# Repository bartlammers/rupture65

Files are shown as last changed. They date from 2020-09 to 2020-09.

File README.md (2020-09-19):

# Rupture65, a split 65% keyboard

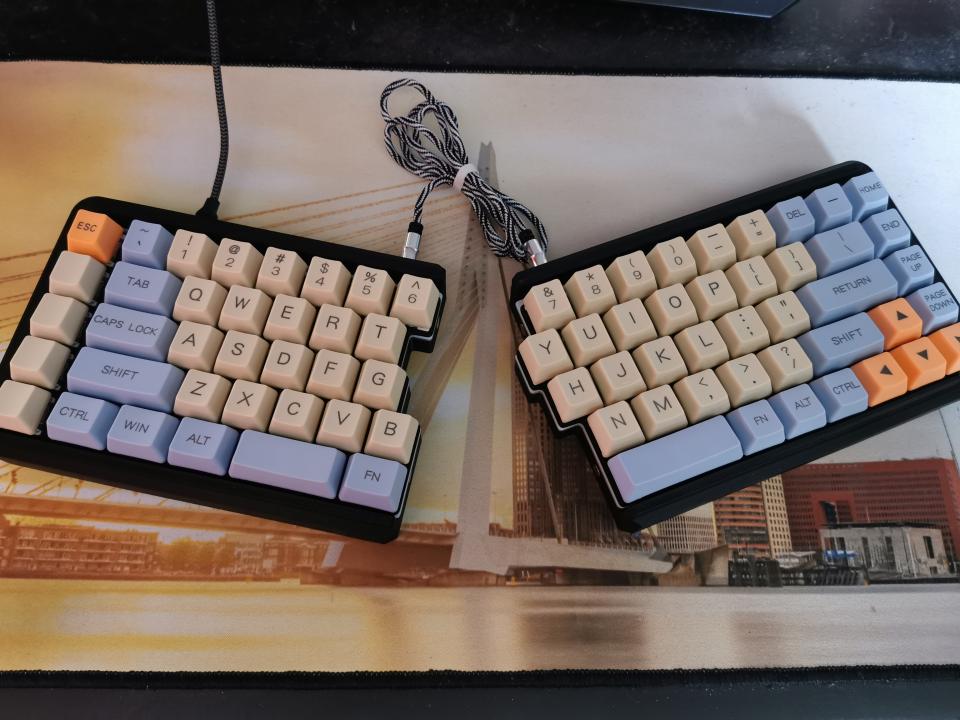
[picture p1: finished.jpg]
Finished Keyboard


## Left

[Project](./Left)  
[iBom](http://htmlpreview.github.io/?https://github.com/bartlammers/rupture65/blob/master/Left/bom/ibom.html)

## Right

[Project](./Right)  
[iBom](http://htmlpreview.github.io/?https://github.com/bartlammers/rupture65/blob/master/Right/bom/ibom.html)

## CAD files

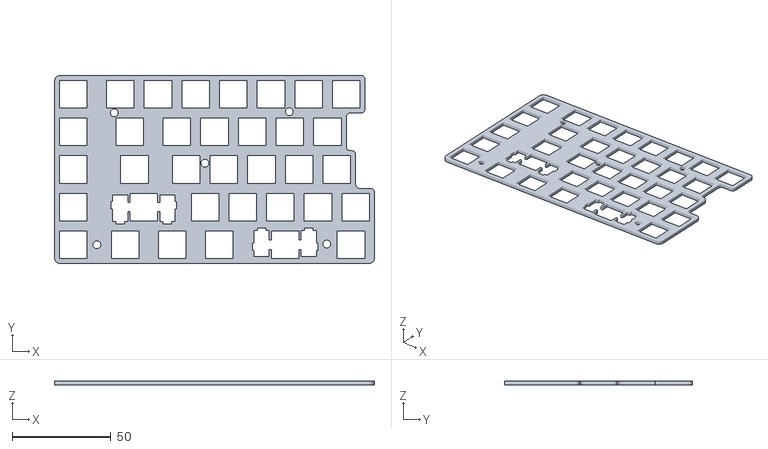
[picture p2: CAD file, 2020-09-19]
Plate/Left.stl
161.9 x 95.3 x 2.00

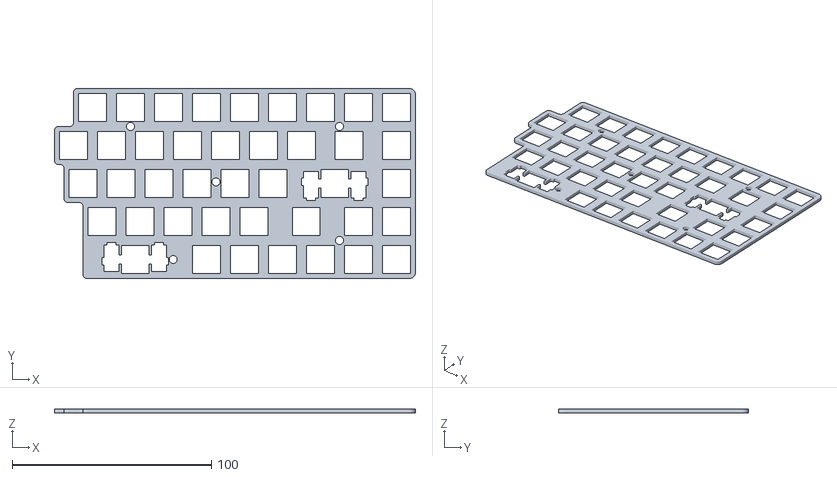
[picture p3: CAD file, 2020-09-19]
Plate/Right.stl
181.0 x 95.3 x 2.00

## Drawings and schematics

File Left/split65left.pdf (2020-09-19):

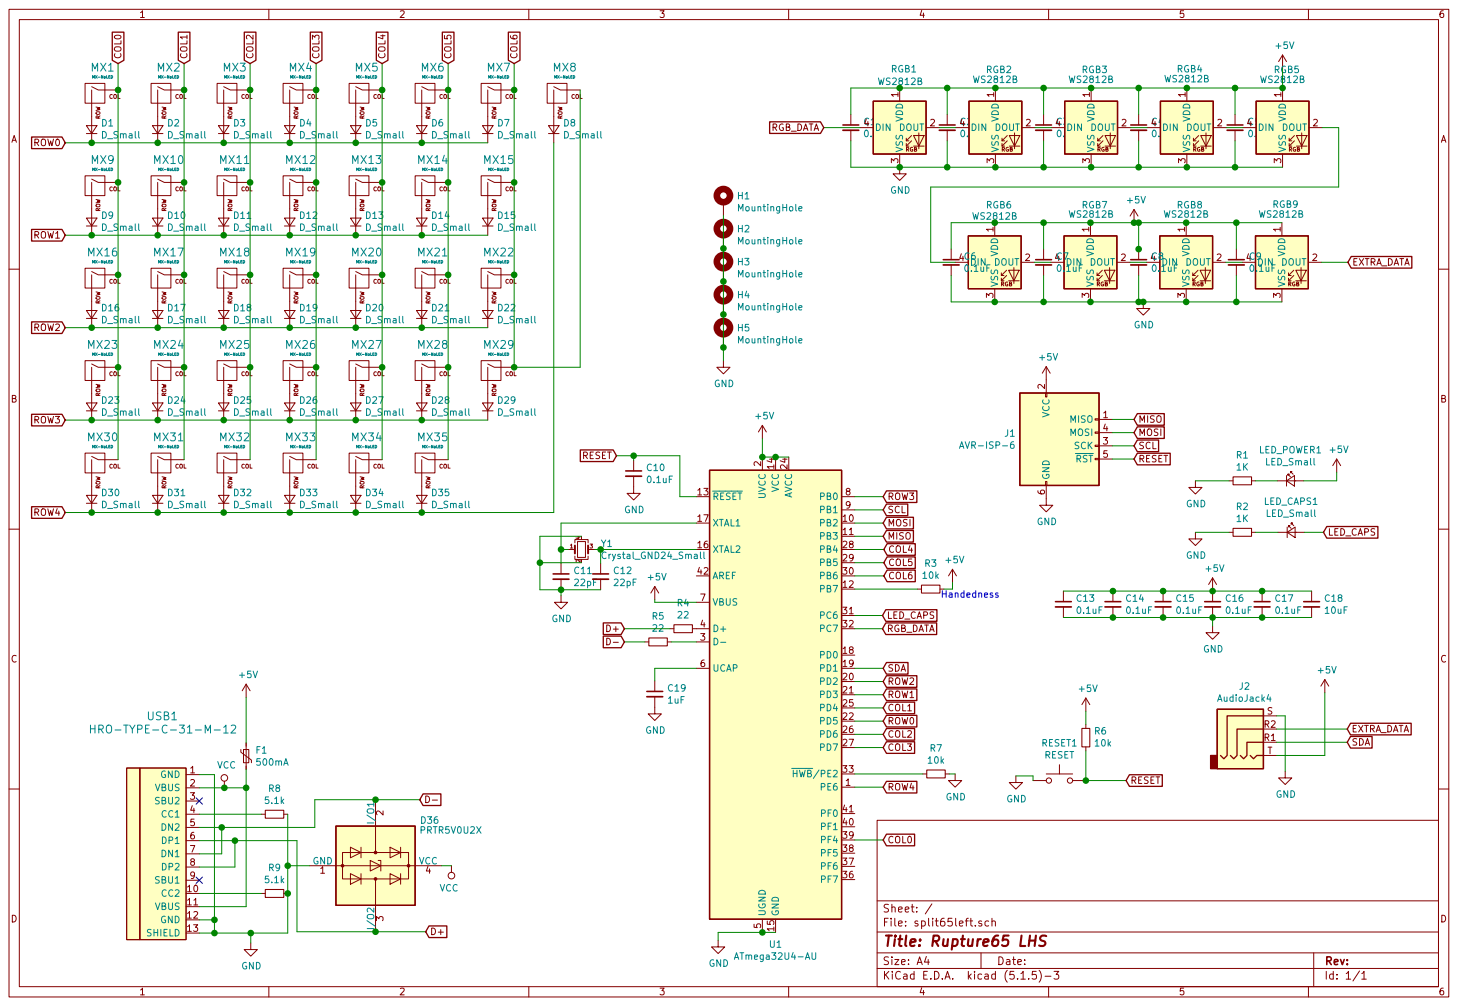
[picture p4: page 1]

MX-NoLED D7D_Small COL ROW MX6

MX-NoLED D4D_Small COL ROW MX24
MX-NoLED D16 D_Small COL ROW MX16

3 DIN 4 RGB8 WS2812B D24 D_Small COL ROW MX9
MX-NoLED D30 D_Small COL ROW MX30

MX-NoLED D13 D_Small COL ROW MX12

MX-NoLED D14 D_Small COL ROW MX13

MX-NoLED D20 D_Small COL ROW MX19

MX-NoLED D23 D_Small COL ROW MX23

2 SCK 3 MOSI 4 RST 5 GND

MX-NoLED D32 D_Small COL ROW MX31

MX-NoLED D34 D_Small COL ROW MX33

MX-NoLED D35 D_Small COL ROW MX34

2 PD2 20 PD3 21 PD5 22 AVCC 24 PD4 25 PD6 26 PD7 27 PB4 28 PB5 29 D- 3 PB6 30 PC6 31 PC7 32 HWB/PE2 33 PF7 36 PF6 37 PF5 38 PF4 39 D+ 4 PF1 40 PF0 41 AREF 42 UGND

5 UCAP 6 VBUS 7 PB0 8 PB1 9 U1 ATmega32U4-AU GND

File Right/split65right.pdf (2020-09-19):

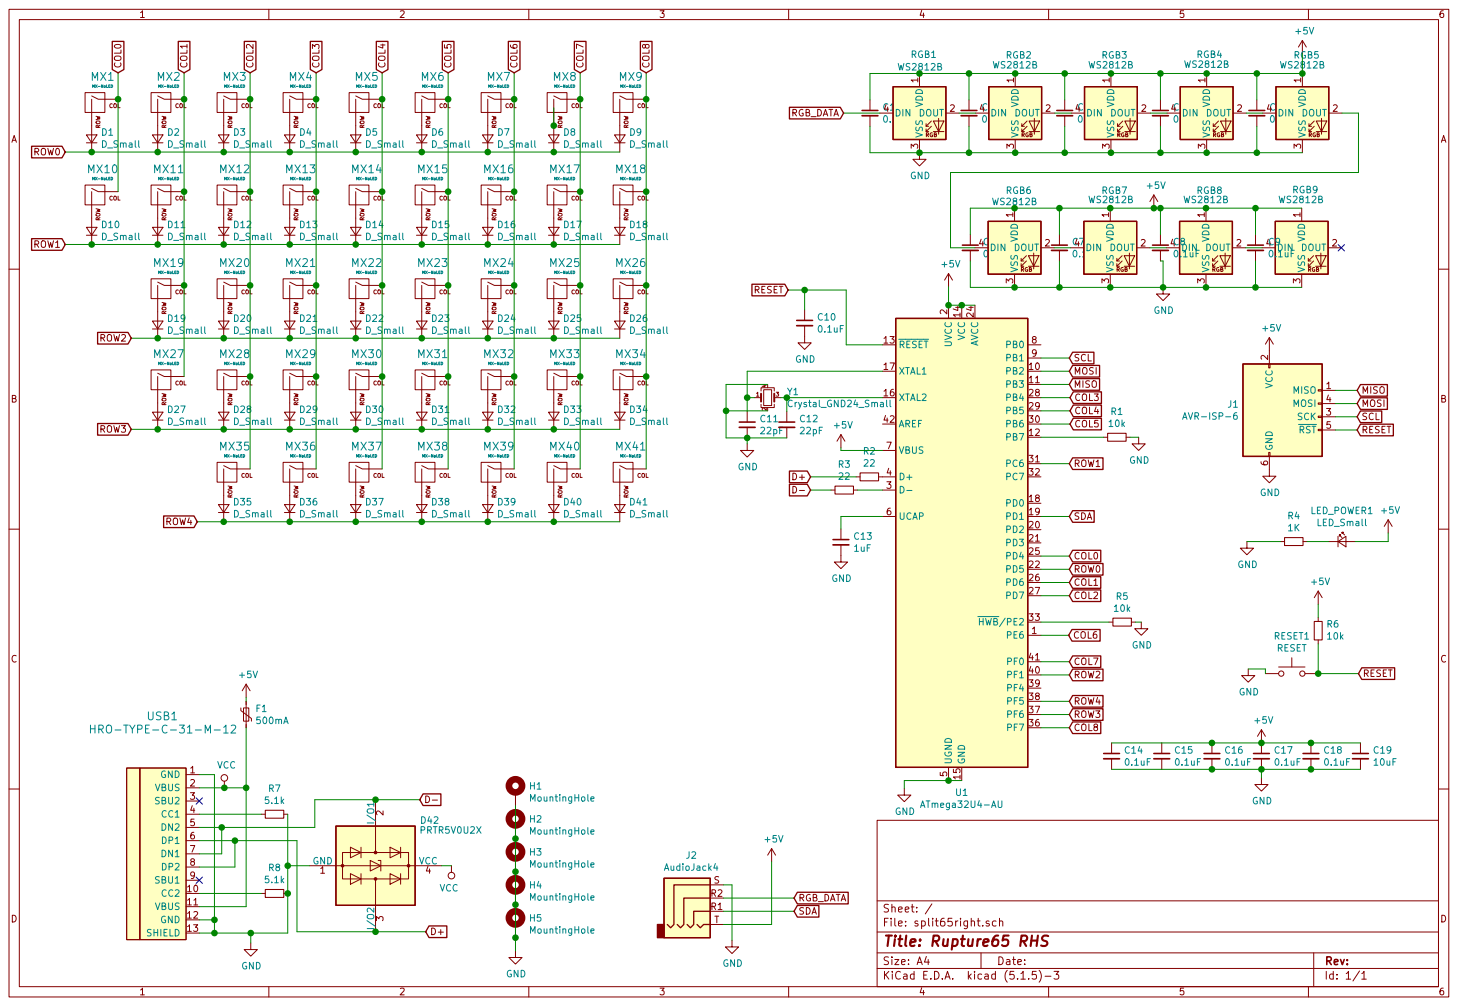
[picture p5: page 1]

MX-NoLED D2D_Small COL ROW MX1

MX-NoLED D3D_Small COL ROW MX2

MX-NoLED D4D_Small COL ROW MX3

+5V D5D_Small COL ROW MX4
MX-NoLED D14 D_Small COL ROW MX13

MX-NoLED D6D_Small COL ROW MX5

MX-NoLED D17 D_Small COL ROW MX8

MX-NoLED D11 D_Small COL ROW MX10

MX-NoLED COL ROW MX11

MX-NoLED D13 D_Small COL ROW MX12

MX-NoLED D16 D_Small COL ROW MX14

MX-NoLED D25 D_Small COL ROW MX16

MX-NoLED D26 D_Small COL ROW MX17

MX-NoLED D21 D_Small COL ROW MX20

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

MX-NoLED COL ROW MX27

MX-NoLED D41 D_Small D28 D_Small COL ROW MX28

2 SCK 3 MOSI 4 RST 5 GND

MX-NoLED COL ROW MX35

MX-NoLED D40 D_Small COL ROW MX38

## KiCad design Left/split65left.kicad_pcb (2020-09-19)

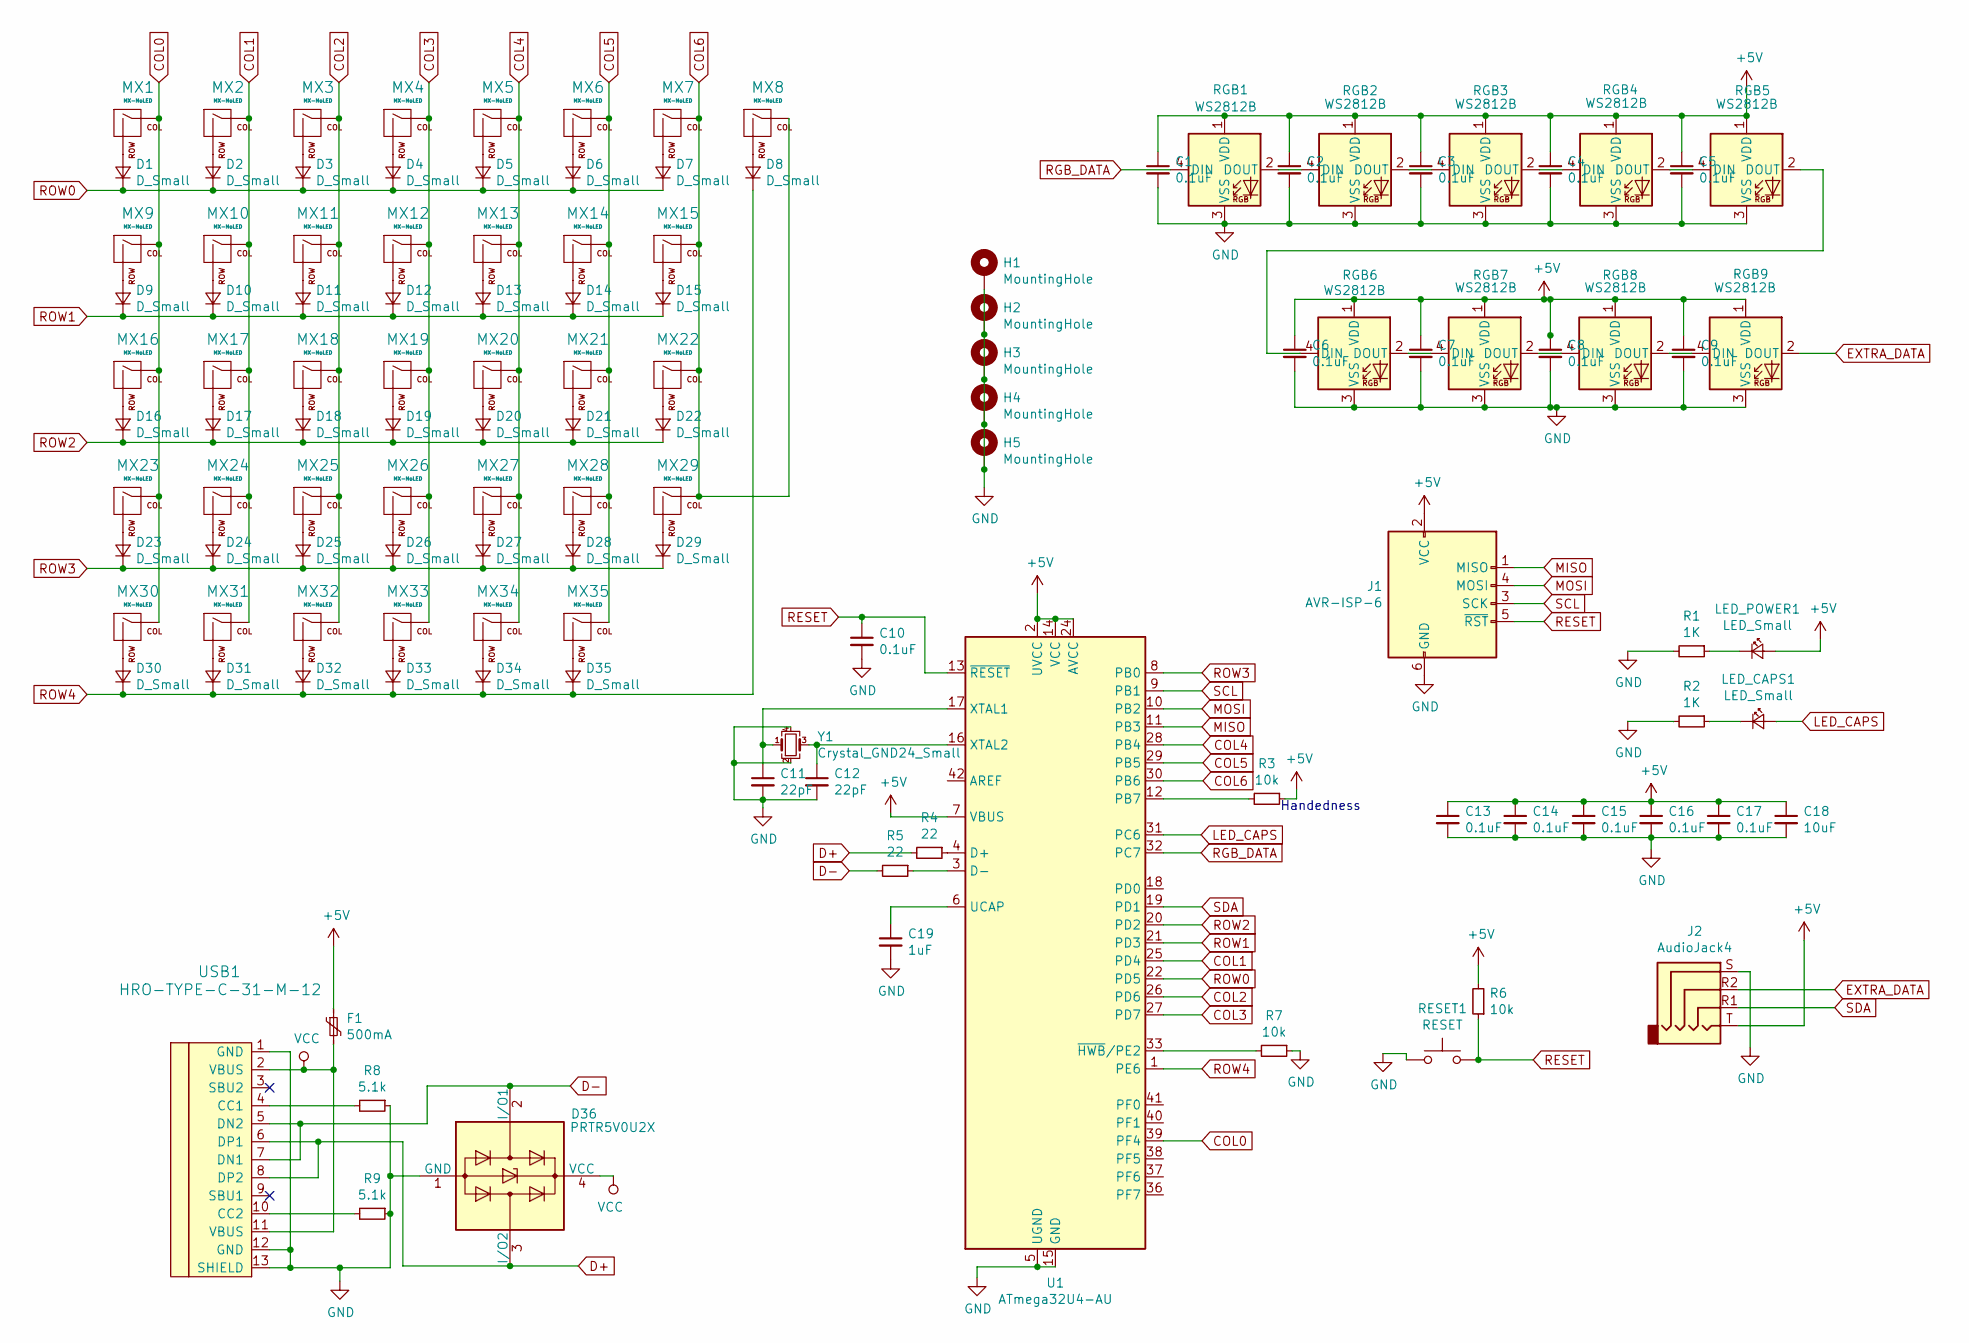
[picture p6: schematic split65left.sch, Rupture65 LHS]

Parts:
C1, C2, C3, C4, C5, C6, C7, C8, C9, C10, C13, C14, C15, C16, C17: 0.1uF; C_0805_2012Metric_Pad1.15x1.40mm_HandSolder
C11, C12: 22pF; C_0805_2012Metric_Pad1.15x1.40mm_HandSolder
C18: 10uF; C_0805_2012Metric_Pad1.15x1.40mm_HandSolder
C19: 1uF; C_0805_2012Metric_Pad1.15x1.40mm_HandSolder
D1, D2, D3, D4, D5, D6, D7, D8, D9, D10, D11, D12, D13, D14, D15, D16, D17, D18, D19, D20, D21, D22, D23, D24, D25, D26, D27, D28, D29, D30, D31, D32, D33, D34, D35: D_Small; D_SOD123_hand
D36: PRTR5V0U2X; SOT-143
F1: 500mA; Fuse_1206_3216Metric_Pad1.42x1.75mm_HandSolder
H1, H2, H3, H4, H5: MountingHole; MountingHole_2.2mm_M2_Pad_Via
J1: AVR-ISP-6; PinHeader_2x03_P2.54mm_Vertical
J2: AudioJack4; PJ-3200B-4A
LED_CAPS1: LED_Small; LED_0805_2012Metric
LED_POWER1: LED_Small; LED_0805_2012Metric
MX1, MX2, MX3, MX4, MX5, MX6, MX7, MX8, MX9, MX11, MX12, MX13, MX14, MX15, MX16, MX18, MX19, MX20, MX21, MX22, MX23, MX25, MX26, MX27, MX28, MX29, MX30: MX-NoLED; SW_Cherry_MX_1.00u_PCB
MX10: MX-NoLED; SW_Cherry_MX_1.50u_PCB
MX17: MX-NoLED; SW_Cherry_MX_1.75u_PCB
MX24: MX-NoLED; SW_Cherry_MX_2.25u_PCB
MX31, MX32, MX33, MX35: MX-NoLED; SW_Cherry_MX_1.25u_PCB
MX34: MX-NoLED; SW_Cherry_MX_2.25u_PCB_flippedstab
R1, R2: 1K; R_0805_2012Metric_Pad1.15x1.40mm_HandSolder
R3, R6, R7: 10k; R_0805_2012Metric_Pad1.15x1.40mm_HandSolder
R4, R5: 22; R_0805_2012Metric_Pad1.15x1.40mm_HandSolder
R8, R9: 5.1k; R_0805_2012Metric_Pad1.15x1.40mm_HandSolder
RESET1: RESET; SW_SPST_SKQG_WithStem
RGB1, RGB2, RGB3, RGB4, RGB5, RGB6, RGB7, RGB8, RGB9: WS2812B; LED_WS2812B_PLCC4_5.0x5.0mm_P3.2mm
U1: ATmega32U4-AU; TQFP-44_10x10mm_P0.8mm
USB1: HRO-TYPE-C-31-M-12; HRO-TYPE-C-31-M-12-HandSoldering
Y1: Crystal_GND24_Small; Crystal_SMD_3225-4Pin_3.2x2.5mm

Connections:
+5V: C1.1, C2.1, C3.1, C4.1, C5.1, C6.1, C7.1, C8.1, C9.1, C13.1, C14.1, C15.1, C16.1, C17.1, C18.1, F1.1, J1.2 (VCC), J2.T, LED_POWER1.2 (A), R3.1, R6.2, RGB1.1 (VDD), RGB2.1 (VDD), RGB3.1 (VDD), RGB4.1 (VDD), RGB5.1 (VDD), RGB6.1 (VDD), RGB7.1 (VDD), RGB8.1 (VDD), RGB9.1 (VDD), U1.2 (UVCC), U1.7 (VBUS), U1.14 (VCC), U1.24 (AVCC), U1.34 (VCC), U1.44 (AVCC)
COL0: MX1.1 (COL), MX9.1 (COL), MX16.1 (COL), MX23.1 (COL), MX30.1 (COL), U1.39 (PF4)
COL1: MX2.1 (COL), MX10.1 (COL), MX17.1 (COL), MX24.1 (COL), MX31.1 (COL), U1.25 (PD4)
COL2: MX3.1 (COL), MX11.1 (COL), MX18.1 (COL), MX25.1 (COL), MX32.1 (COL), U1.26 (PD6)
COL3: MX4.1 (COL), MX12.1 (COL), MX19.1 (COL), MX26.1 (COL), MX33.1 (COL), U1.27 (PD7)
COL4: MX5.1 (COL), MX13.1 (COL), MX20.1 (COL), MX27.1 (COL), MX34.1 (COL), U1.28 (PB4)
COL5: MX6.1 (COL), MX14.1 (COL), MX21.1 (COL), MX28.1 (COL), MX35.1 (COL), U1.29 (PB5)
COL6: MX7.1 (COL), MX8.1 (COL), MX15.1 (COL), MX22.1 (COL), MX29.1 (COL), U1.30 (PB6)
D+: D36.3 (I/O2), R4.2, USB1.6 (DP1), USB1.8 (DP2)
D-: D36.2 (I/O1), R5.2, USB1.5 (DN2), USB1.7 (DN1)
EXTRA_DATA: J2.R2, RGB9.2 (DOUT)
GND: C1.2, C2.2, C3.2, C4.2, C5.2, C6.2, C7.2, C8.2, C9.2, C10.2, C11.2, C12.2, C13.2, C14.2, C15.2, C16.2, C17.2, C18.2, C19.2, D36.1 (GND), H1.1, H2.1, H3.1, H4.1, H5.1, J1.6 (GND), J2.S, R1.2, R2.2, R7.1, R8.1, R9.1, RESET1.1, RGB1.3 (VSS), RGB2.3 (VSS), RGB3.3 (VSS), RGB4.3 (VSS), RGB5.3 (VSS), RGB6.3 (VSS), RGB7.3 (VSS), RGB8.3 (VSS), RGB9.3 (VSS), U1.5 (UGND), U1.15 (GND), U1.23 (GND), U1.35 (GND), U1.43 (GND), USB1.1 (GND), USB1.12 (GND), USB1.13 (SHIELD), Y1.2, Y1.4
LED_CAPS: LED_CAPS1.2 (A), U1.31 (PC6)
MISO: J1.1 (MISO), U1.11 (PB3)
MOSI: J1.4 (MOSI), U1.10 (PB2)
unnamed: C11.1, U1.17 (XTAL1), Y1.1
unnamed: C12.1, U1.16 (XTAL2), Y1.3
unnamed: C19.1, U1.6 (UCAP)
unnamed: D1.2 (A), MX1.2 (ROW)
unnamed: D2.2 (A), MX2.2 (ROW)
unnamed: D3.2 (A), MX3.2 (ROW)
unnamed: D4.2 (A), MX4.2 (ROW)
unnamed: D5.2 (A), MX5.2 (ROW)
unnamed: D6.2 (A), MX6.2 (ROW)
unnamed: D7.2 (A), MX7.2 (ROW)
unnamed: D8.2 (A), MX8.2 (ROW)
unnamed: D9.2 (A), MX9.2 (ROW)
unnamed: D10.2 (A), MX10.2 (ROW)
unnamed: D11.2 (A), MX11.2 (ROW)
unnamed: D12.2 (A), MX12.2 (ROW)
unnamed: D13.2 (A), MX13.2 (ROW)
unnamed: D14.2 (A), MX14.2 (ROW)
unnamed: D15.2 (A), MX15.2 (ROW)
unnamed: D16.2 (A), MX16.2 (ROW)
unnamed: D17.2 (A), MX17.2 (ROW)
unnamed: D18.2 (A), MX18.2 (ROW)
unnamed: D19.2 (A), MX19.2 (ROW)
unnamed: D20.2 (A), MX20.2 (ROW)
unnamed: D21.2 (A), MX21.2 (ROW)
unnamed: D22.2 (A), MX22.2 (ROW)
unnamed: D23.2 (A), MX23.2 (ROW)
unnamed: D24.2 (A), MX24.2 (ROW)
unnamed: D25.2 (A), MX25.2 (ROW)
unnamed: D26.2 (A), MX26.2 (ROW)
unnamed: D27.2 (A), MX27.2 (ROW)
unnamed: D28.2 (A), MX28.2 (ROW)
unnamed: D29.2 (A), MX29.2 (ROW)
unnamed: D30.2 (A), MX30.2 (ROW)
unnamed: D31.2 (A), MX31.2 (ROW)
unnamed: D32.2 (A), MX32.2 (ROW)
unnamed: D33.2 (A), MX33.2 (ROW)
unnamed: D34.2 (A), MX34.2 (ROW)
unnamed: D35.2 (A), MX35.2 (ROW)
unnamed: LED_CAPS1.1 (K), R2.1
unnamed: LED_POWER1.1 (K), R1.1
unnamed: R3.2, U1.12 (PB7)
unnamed: R4.1, U1.4 (D+)
unnamed: R5.1, U1.3 (D-)
unnamed: R7.2, U1.33 (~HWB~/PE2)
unnamed: R8.2, USB1.4 (CC1)
unnamed: R9.2, USB1.10 (CC2)
unnamed: RGB1.2 (DOUT), RGB2.4 (DIN)
unnamed: RGB2.2 (DOUT), RGB3.4 (DIN)
unnamed: RGB3.2 (DOUT), RGB4.4 (DIN)
unnamed: RGB4.2 (DOUT), RGB5.4 (DIN)
unnamed: RGB5.2 (DOUT), RGB6.4 (DIN)
unnamed: RGB6.2 (DOUT), RGB7.4 (DIN)
unnamed: RGB7.2 (DOUT), RGB8.4 (DIN)
unnamed: RGB8.2 (DOUT), RGB9.4 (DIN)
RESET: C10.1, J1.5 (~RST), R6.1, RESET1.2, U1.13 (~RESET)
RGB_DATA: RGB1.4 (DIN), U1.32 (PC7)
ROW0: D1.1 (K), D2.1 (K), D3.1 (K), D4.1 (K), D5.1 (K), D6.1 (K), D7.1 (K), U1.22 (PD5)
ROW1: D9.1 (K), D10.1 (K), D11.1 (K), D12.1 (K), D13.1 (K), D14.1 (K), D15.1 (K), U1.21 (PD3)
ROW2: D16.1 (K), D17.1 (K), D18.1 (K), D19.1 (K), D20.1 (K), D21.1 (K), D22.1 (K), U1.20 (PD2)
ROW3: D23.1 (K), D24.1 (K), D25.1 (K), D26.1 (K), D27.1 (K), D28.1 (K), D29.1 (K), U1.8 (PB0)
ROW4: D8.1 (K), D30.1 (K), D31.1 (K), D32.1 (K), D33.1 (K), D34.1 (K), D35.1 (K), U1.1 (PE6)
SCL: J1.3 (SCK), U1.9 (PB1)
SDA: J2.R1, U1.19 (PD1)
VCC: D36.4 (VCC), F1.2, USB1.2 (VBUS), USB1.11 (VBUS)

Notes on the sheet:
Handedness

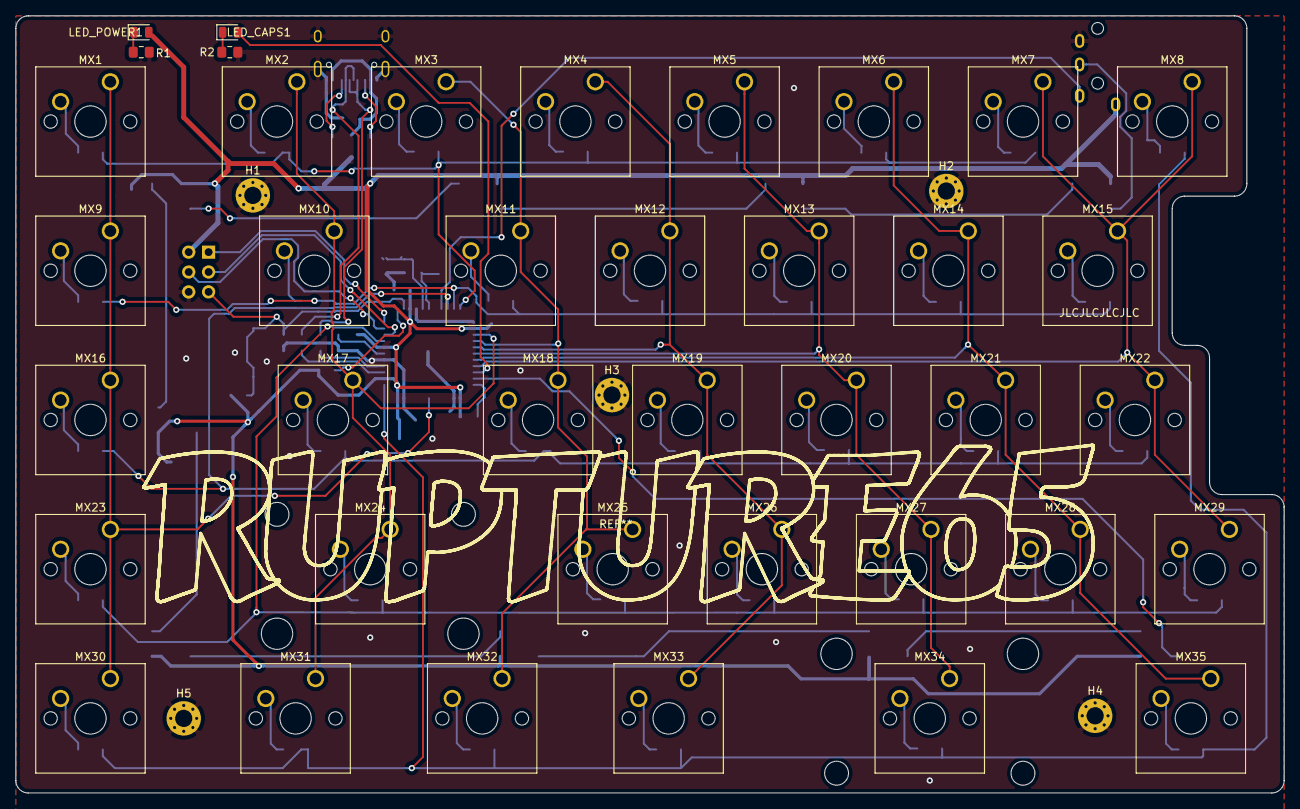
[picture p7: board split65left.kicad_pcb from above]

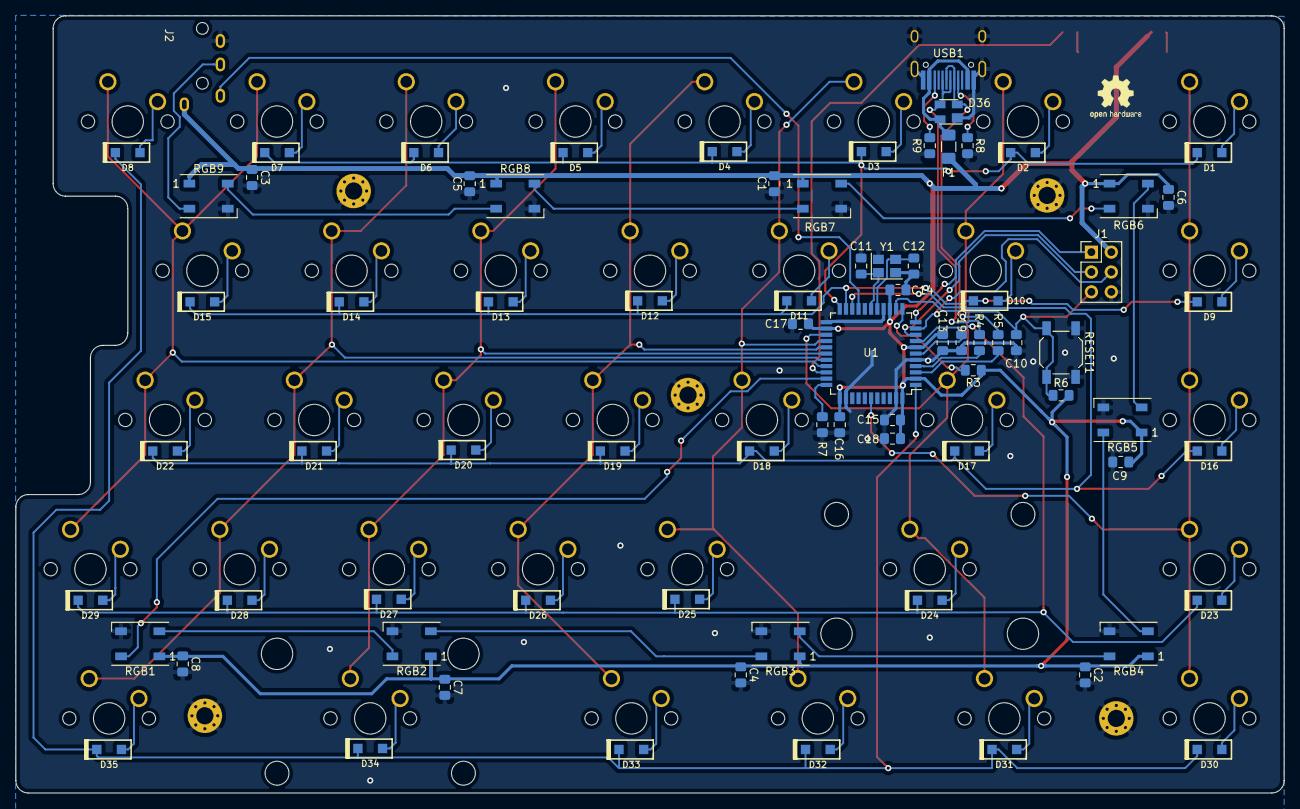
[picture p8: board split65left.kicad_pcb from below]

Board: 2 copper layers, 161.9 x 99.2 mm, 122 parts (78 on the bottom side), 79 nets.
